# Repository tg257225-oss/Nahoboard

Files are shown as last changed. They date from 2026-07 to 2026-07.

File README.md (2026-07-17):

# Nahoboard
A simple development board that allows the user to prototype, write code, and test hardware functions without needing to design a custom PCB. It is inspired by the protagonist of Atlus' Shin Megami Tensei V game (in their Aogami form).

Renders:
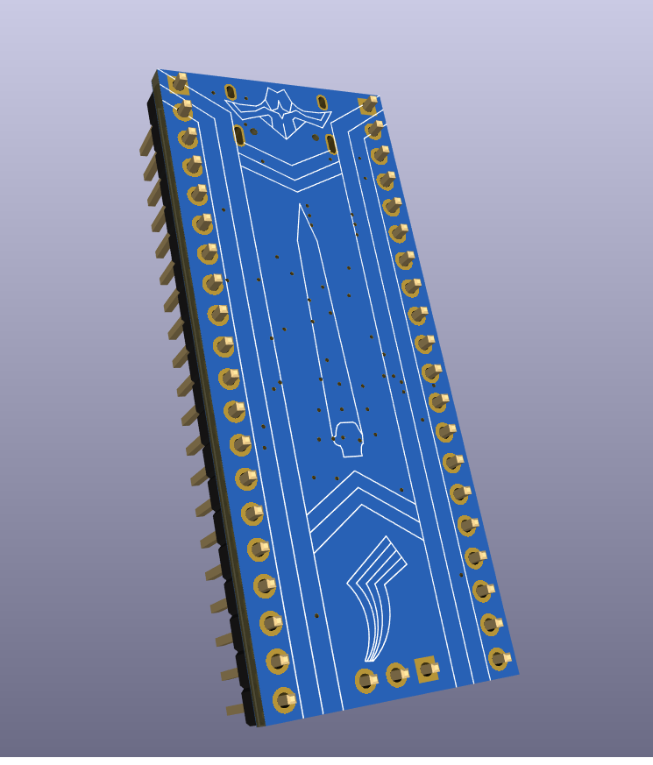
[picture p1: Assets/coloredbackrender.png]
PCB Back
### 
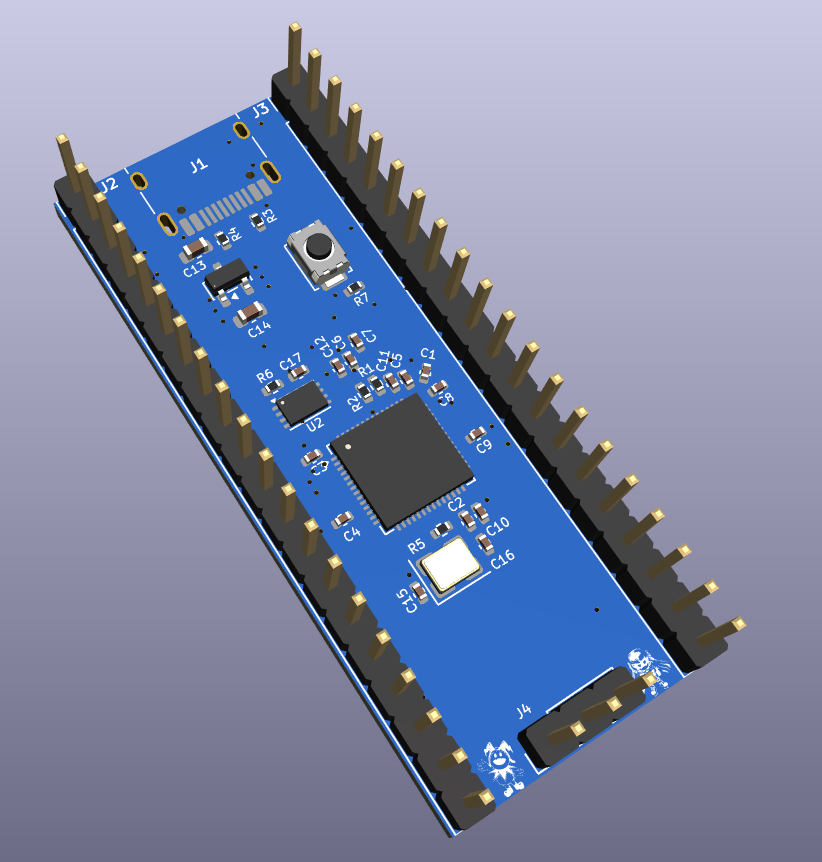
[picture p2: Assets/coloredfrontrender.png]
PCB Front
### 

## Features (really standard stuff for a devboard)
* USB-C for easy connections
* A push button
* 12MHz Crystal

## Production
Everything in the 'Production' folder can be used to have this PCB manufactured by JLCPCB.

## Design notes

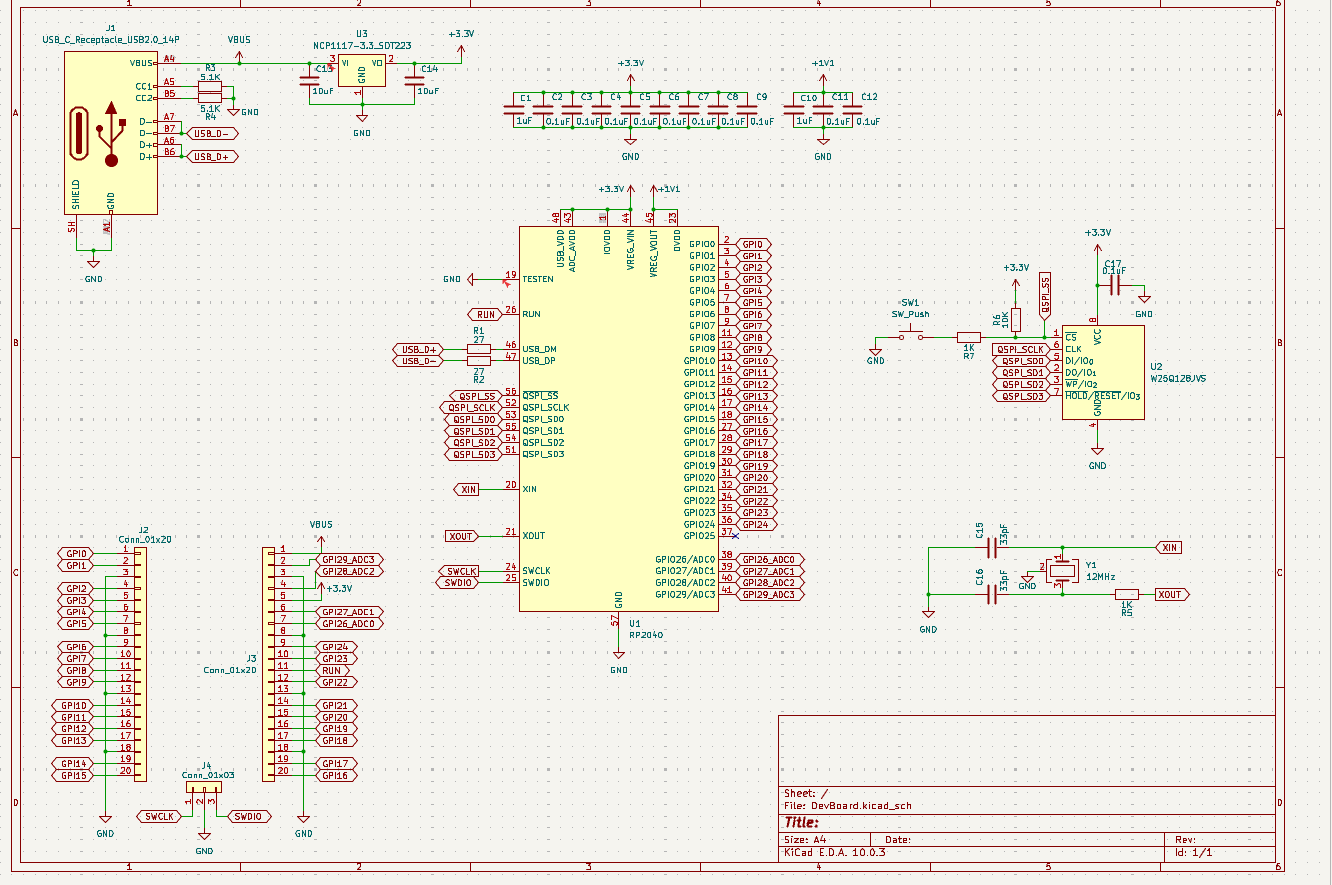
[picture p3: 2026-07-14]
Assets/nahoboardschematicsofar.png

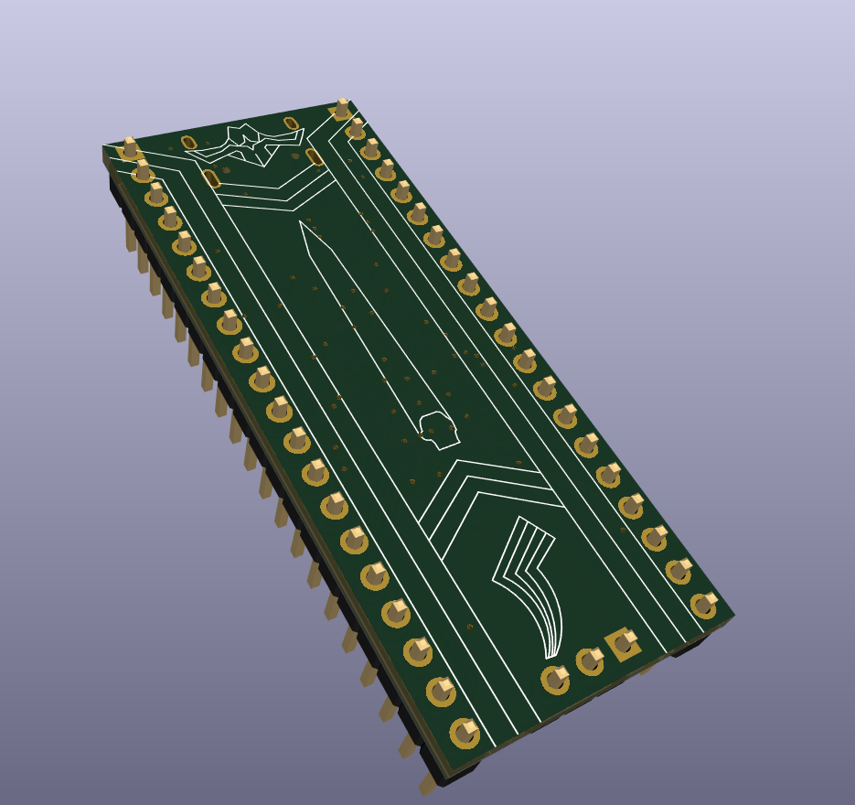
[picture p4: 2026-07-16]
Assets/backdesign.png

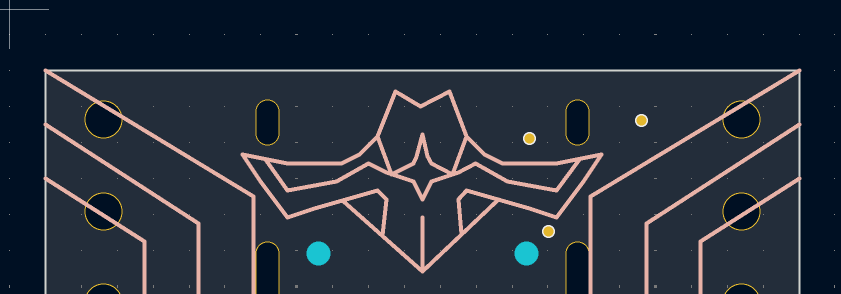
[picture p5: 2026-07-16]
Assets/morenahobinostuff.png

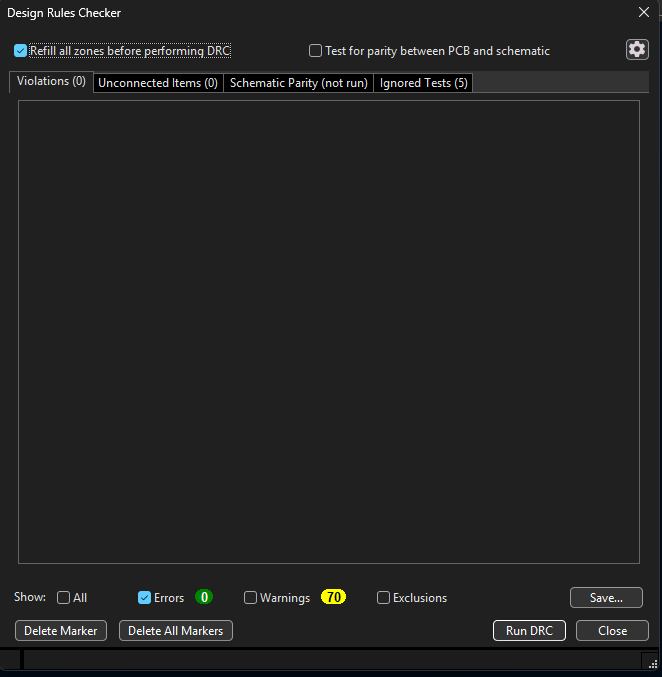
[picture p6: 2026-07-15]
Assets/noviolationsomg.png

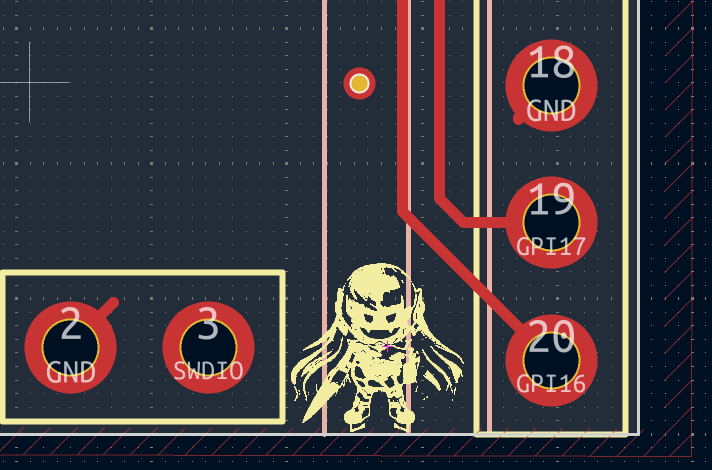
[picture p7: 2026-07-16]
Assets/nahobeehoreference.png

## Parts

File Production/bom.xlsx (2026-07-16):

Item | Qty | Reference | Value | Est. Unit Price | Est. Extended Price
1 | 2 | C1, C10 | 1μF | $0.05 | $0.10
2 | 11 | C2-C9, C11, C12, C17 | 0.1μF | $0.05 | $0.55
3 | 2 | C13, C14 | 10μF | $0.05 | $0.10
4 | 2 | C15, C16 | 33pF | $0.05 | $0.10
5 | 1 | J1 | USB-C 2.0 | $0.60 | $0.60
6 | 2 | J2, J3 | 20-pin Header | $0.40 | $0.80
7 | 1 | J4 | 3-pin Header | $0.15 | $0.15
8 | 2 | R1, R2 | 27Ω | $0.05 | $0.10
9 | 2 | R3, R4 | 5.1kΩ | $0.05 | $0.10
10 | 2 | R5, R7 | 1kΩ | $0.05 | $0.10
11 | 1 | R6 | 10kΩ | $0.05 | $0.05
12 | 1 | SW1 | Push Button | $0.25 | $0.25
13 | 1 | U1 (RP2040) | Microcontroller | $0.92 | $0.92
14 | 1 | U2 | 128Mbit Flash | $3.72 | $3.72
15 | 1 | U4 | 3.3V LDO | $0.51 | $0.51
16 | 1 | Y1 | 12MHz Crystal | $0.30 | $0.30
Total | 33 |  |  |  | $8.45

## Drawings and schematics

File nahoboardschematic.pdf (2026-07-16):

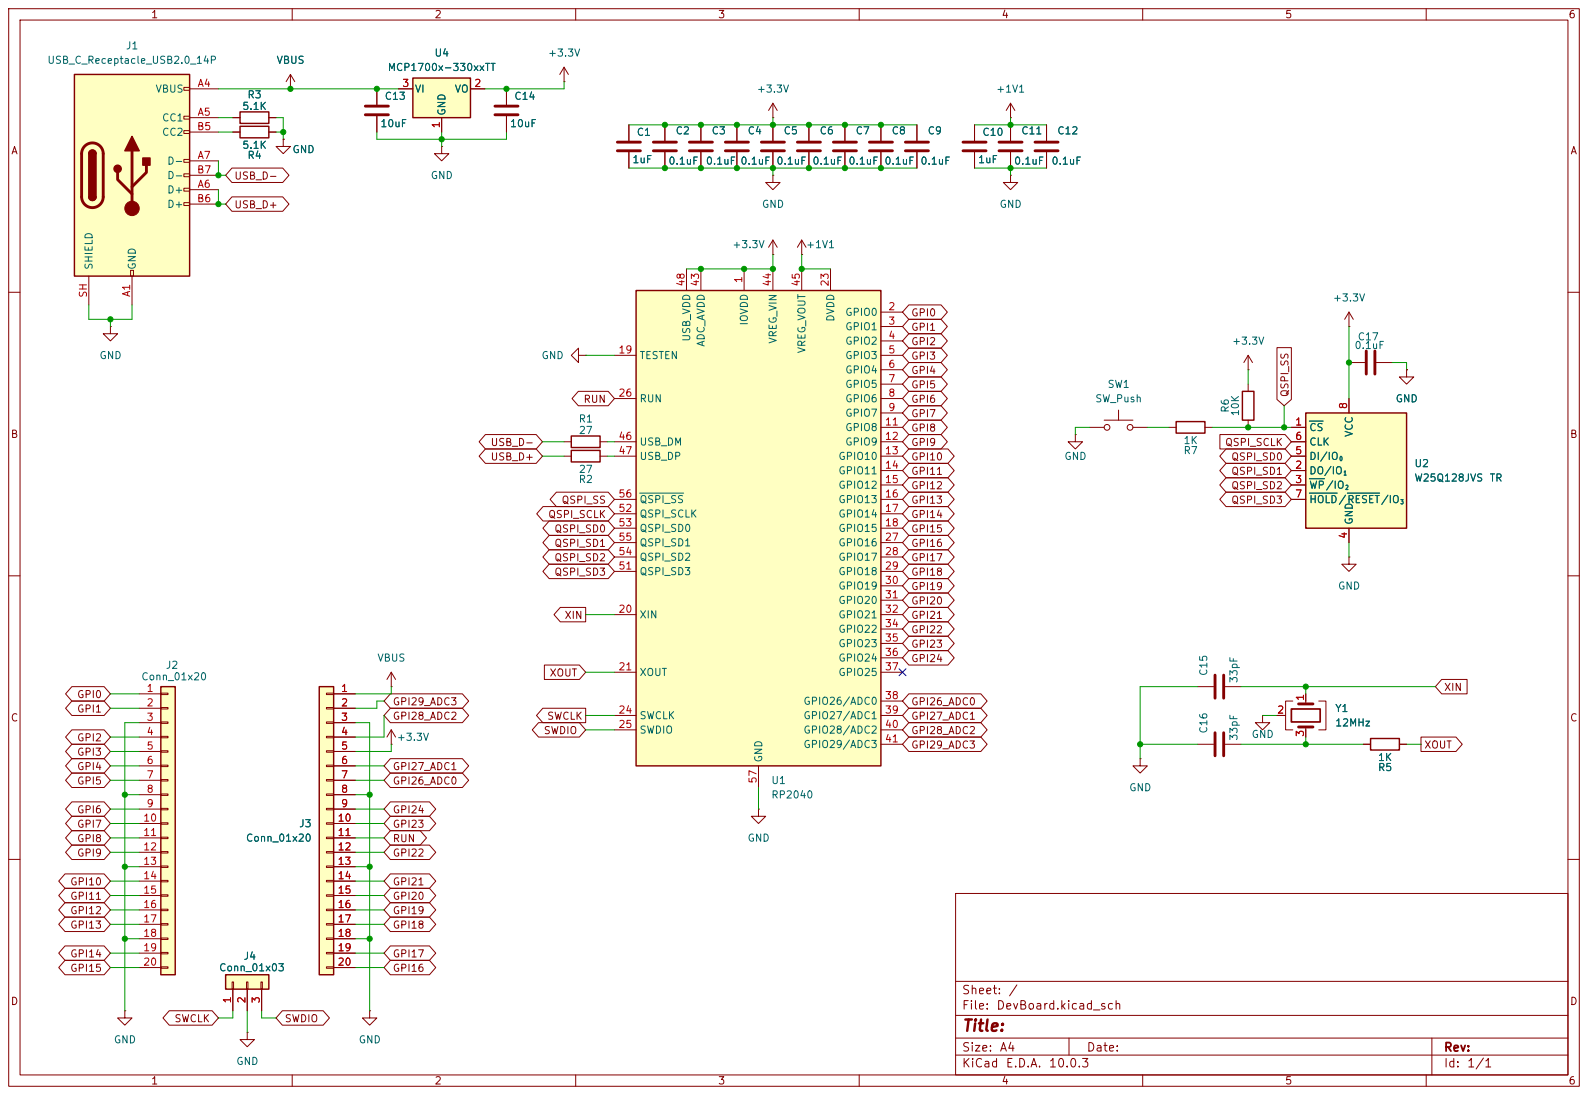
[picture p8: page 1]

4 DI/IO0 5 CLK 6 HOLD/RESET/IO3 7 VCC

Size: A4 | Rev:
KiCad E.D.A. 10.0.3 | Id: 1/1

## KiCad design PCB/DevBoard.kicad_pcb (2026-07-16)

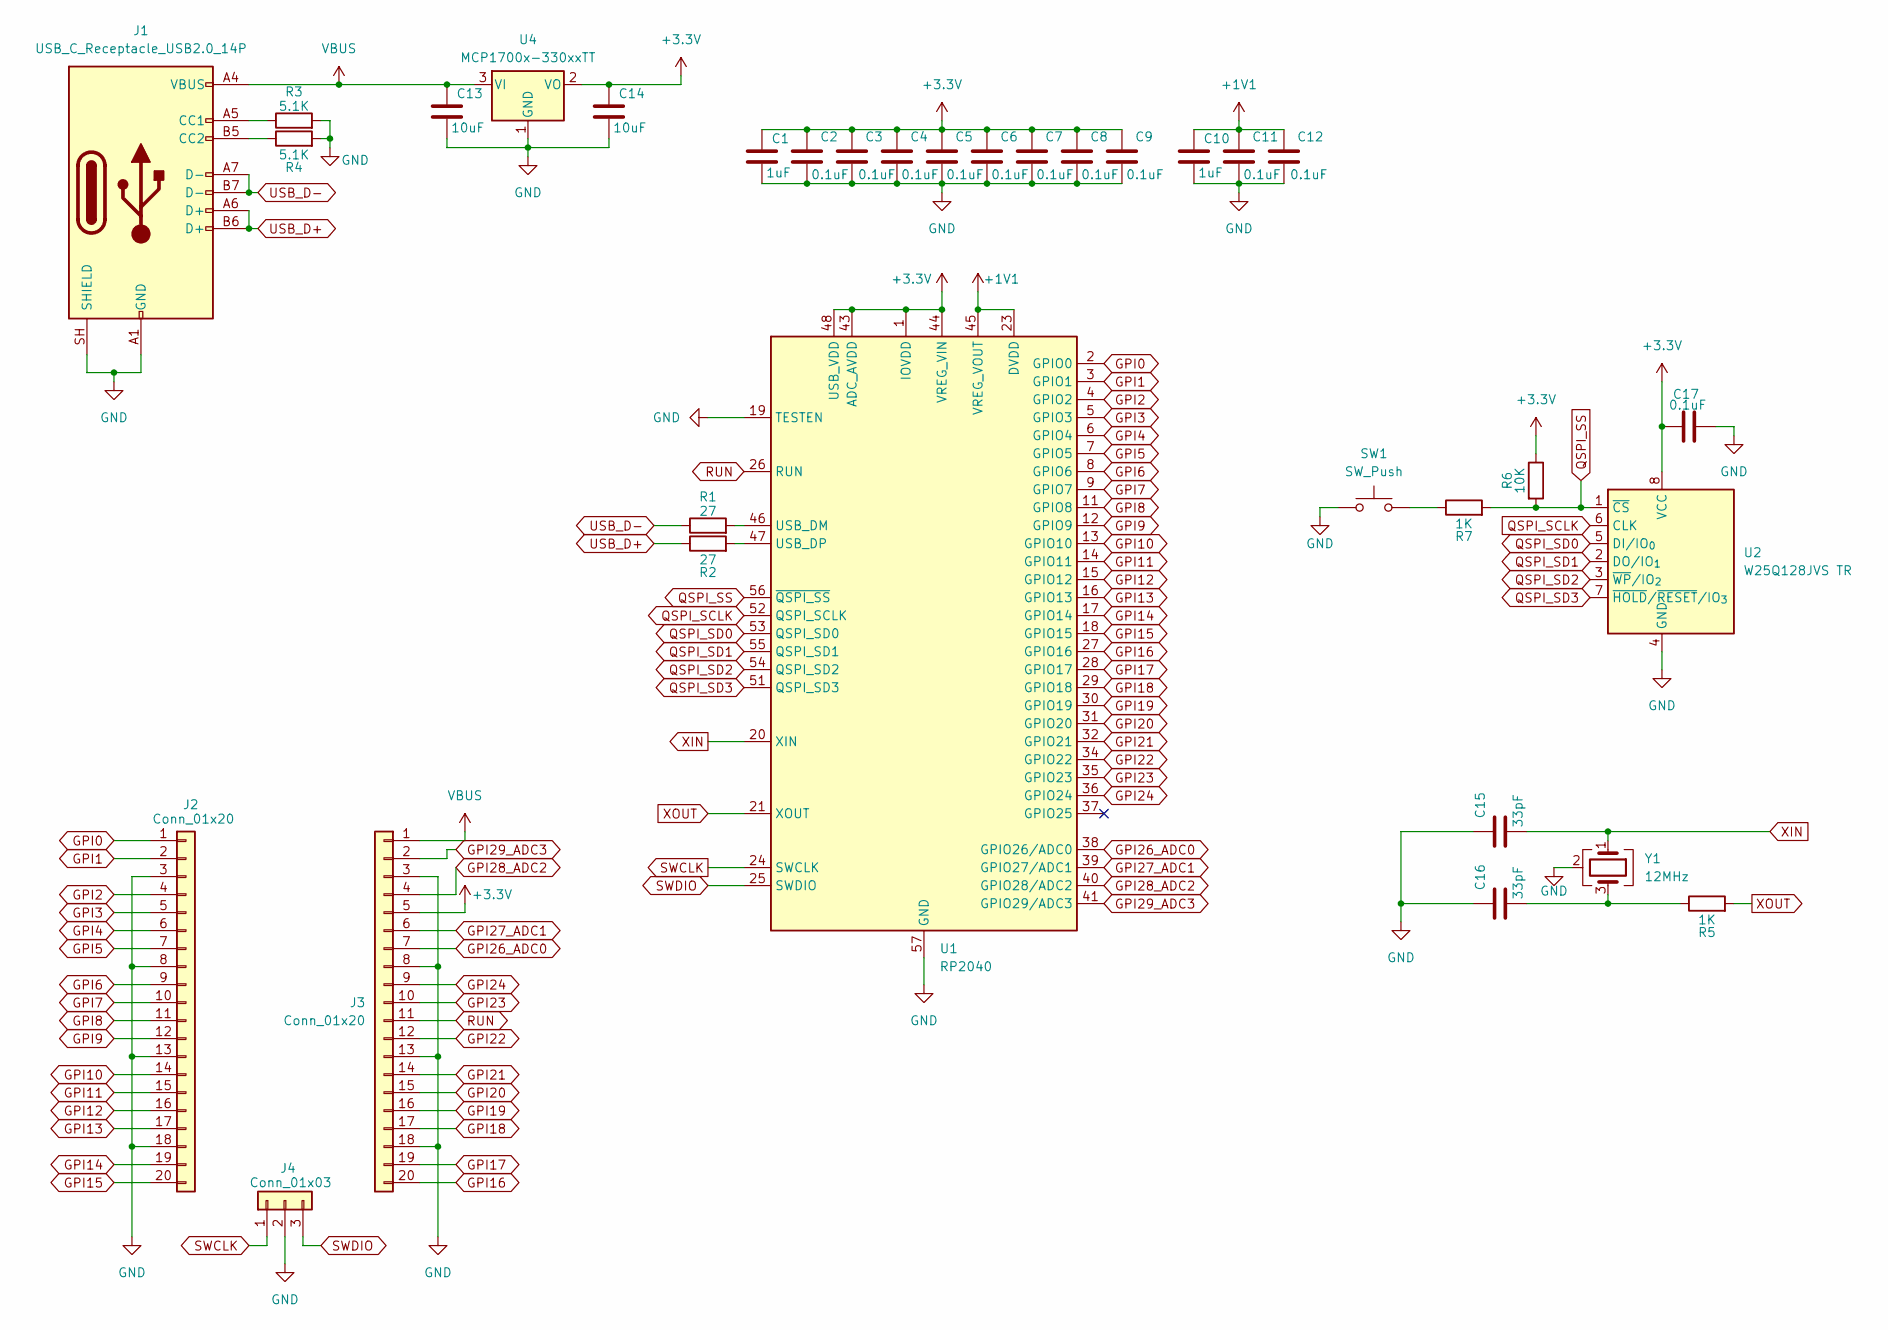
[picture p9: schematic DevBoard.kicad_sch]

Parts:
C1, C10: 1uF; C_0402_1005Metric
C2, C3, C4, C5, C6, C7, C8, C9, C11, C12, C17: 0.1uF; C_0402_1005Metric
C13, C14: 10uF; C_0603_1608Metric
C15, C16: 33pF; C_0402_1005Metric
J1: USB_C_Receptacle_USB2.0_14P; USB_C_Receptacle_HRO_TYPE-C-31-M-12
J2, J3: Conn_01x20; PinHeader_1x20_P2.54mm_Vertical
J4: Conn_01x03; PinHeader_1x03_P2.54mm_Vertical
R1, R2: 27; R_0402_1005Metric
R3, R4: 5.1K; R_0402_1005Metric
R5, R7: 1K; R_0402_1005Metric
R6: 10K; R_0402_1005Metric
SW1: SW_Push; SW_Push_SPST_NO_Alps_SKRK
U1: RP2040; QFN-56-1EP_7x7mm_P0.4mm_EP3.2x3.2mm
U2: W25Q128JVS TR; Winbond_USON-8-1EP_3x2mm_P0.5mm_EP0.2x1.6mm
U4: MCP1700x-330xxTT; SOT-23
Y1: 12MHz; Crystal_SMD_3225-4Pin_3.2x2.5mm

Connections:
+1V1: C10.1, C11.1, C12.1, U1.23 (DVDD), U1.45 (VREG_VOUT), U1.50 (DVDD)
+3.3V: C1.1, C2.1, C3.1, C4.1, C5.1, C6.1, C7.1, C8.1, C9.1, C14.1, C17.1, J3.5, R6.1, U1.1 (IOVDD), U1.10 (IOVDD), U1.22 (IOVDD), U1.33 (IOVDD), U1.42 (IOVDD), U1.43 (ADC_AVDD), U1.44 (VREG_VIN), U1.48 (USB_VDD), U1.49 (IOVDD), U2.8 (VCC), U4.2 (VO)
GND: C1.2, C2.2, C3.2, C4.2, C5.2, C6.2, C7.2, C8.2, C9.2, C10.2, C11.2, C12.2, C13.2, C14.2, C15.1, C16.1, C17.2, J1.A1 (GND), J1.A12 (GND), J1.B1 (GND), J1.B12 (GND), J1.SH (SHIELD), J2.3, J2.8, J2.13, J2.18, J3.3, J3.8, J3.13, J3.18, J4.2, R3.2, R4.2, SW1.1, U1.19 (TESTEN), U1.57 (GND), U2.4 (GND), U4.1 (GND), Y1.2 (G), Y1.4 (G)
GPI0: J2.1, U1.2 (GPIO0)
GPI1: J2.2, U1.3 (GPIO1)
GPI2: J2.4, U1.4 (GPIO2)
GPI3: J2.5, U1.5 (GPIO3)
GPI4: J2.6, U1.6 (GPIO4)
GPI5: J2.7, U1.7 (GPIO5)
GPI6: J2.9, U1.8 (GPIO6)
GPI7: J2.10, U1.9 (GPIO7)
GPI8: J2.11, U1.11 (GPIO8)
GPI9: J2.12, U1.12 (GPIO9)
GPI10: J2.14, U1.13 (GPIO10)
GPI11: J2.15, U1.14 (GPIO11)
GPI12: J2.16, U1.15 (GPIO12)
GPI13: J2.17, U1.16 (GPIO13)
GPI14: J2.19, U1.17 (GPIO14)
GPI15: J2.20, U1.18 (GPIO15)
GPI16: J3.20, U1.27 (GPIO16)
GPI17: J3.19, U1.28 (GPIO17)
GPI18: J3.17, U1.29 (GPIO18)
GPI19: J3.16, U1.30 (GPIO19)
GPI20: J3.15, U1.31 (GPIO20)
GPI21: J3.14, U1.32 (GPIO21)
GPI22: J3.12, U1.34 (GPIO22)
GPI23: J3.10, U1.35 (GPIO23)
GPI24: J3.9, U1.36 (GPIO24)
GPI26_ADC0: J3.7, U1.38 (GPIO26/ADC0)
GPI27_ADC1: J3.6, U1.39 (GPIO27/ADC1)
GPI28_ADC2: J3.4, U1.40 (GPIO28/ADC2)
GPI29_ADC3: J3.2, U1.41 (GPIO29/ADC3)
unnamed: C16.2, R5.1, Y1.3
unnamed: J1.A5 (CC1), R3.1
unnamed: J1.B5 (CC2), R4.1
unnamed: R7.1, SW1.2
unnamed: R1.2, U1.46 (USB_DM)
unnamed: R2.2, U1.47 (USB_DP)
QSPI_SCLK: U1.52 (QSPI_SCLK), U2.6 (CLK)
QSPI_SD0: U1.53 (QSPI_SD0), U2.5 (DI/IO_{0})
QSPI_SD1: U1.55 (QSPI_SD1), U2.2 (DO/IO_{1})
QSPI_SD2: U1.54 (QSPI_SD2), U2.3 (~WP/IO_{2})
QSPI_SD3: U1.51 (QSPI_SD3), U2.7 (~HOLD/~RESET/IO_{3})
QSPI_SS: R6.2, R7.2, U1.56 (~QSPI_SS), U2.1 (~CS)
RUN: J3.11, U1.26 (RUN)
SWCLK: J4.1, U1.24 (SWCLK)
SWDIO: J4.3, U1.25 (SWDIO)
USB_D+: J1.A6 (D+), J1.B6 (D+), R2.1
USB_D-: J1.A7 (D-), J1.B7 (D-), R1.1
VBUS: C13.1, J1.A4 (VBUS), J1.A9 (VBUS), J1.B4 (VBUS), J1.B9 (VBUS), J3.1, U4.3 (VI)
XIN: C15.2, U1.20 (XIN), Y1.1
XOUT: R5.2, U1.21 (XOUT)

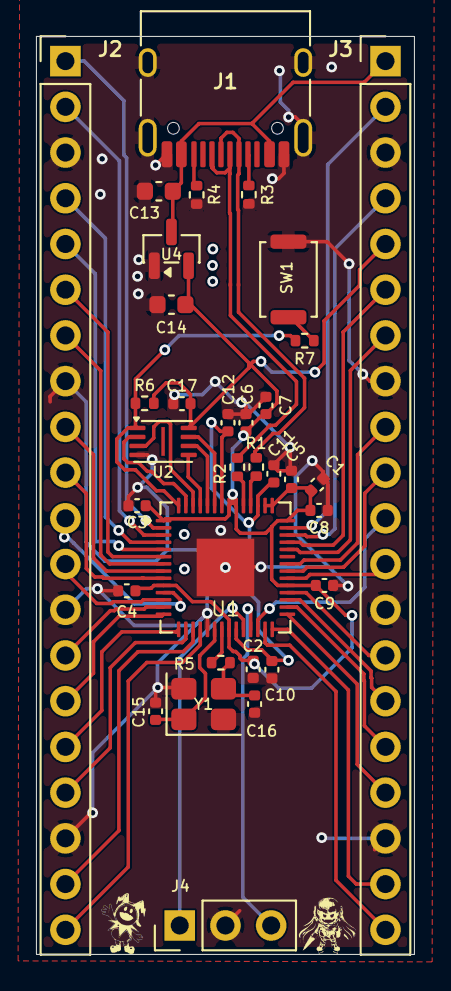
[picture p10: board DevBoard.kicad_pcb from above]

Board: 2 copper layers, 21.0 x 51.0 mm, 33 parts (0 on the bottom side), 52 nets.

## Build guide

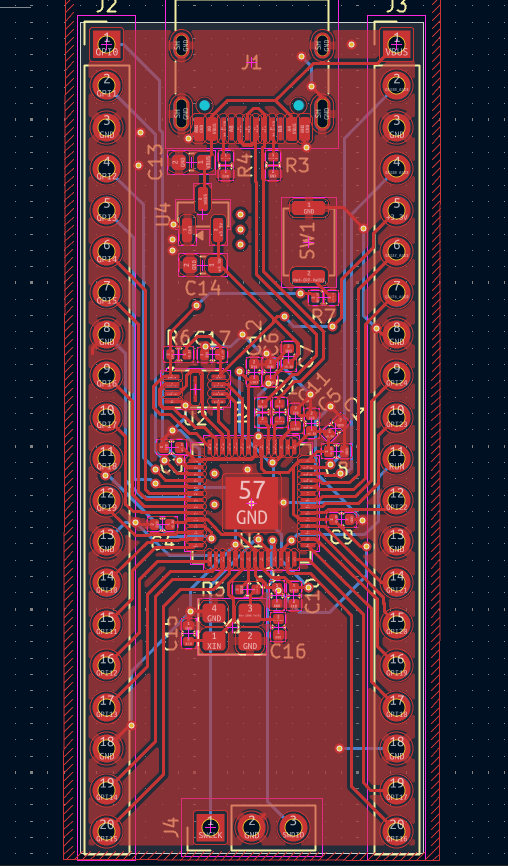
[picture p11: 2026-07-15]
Assets/practicallydonewiring.png

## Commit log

2026-07-16 Add PCB back render image to README
    Added a render image of the PCB back to the README.
2026-07-16 Include front PCB render in README
    Added front PCB render image to README.
2026-07-17 Add production section to README
    Added production information for PCB manufacturing.
